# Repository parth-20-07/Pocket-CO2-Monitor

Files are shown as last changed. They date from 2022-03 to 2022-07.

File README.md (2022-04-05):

# Pocket Carbondioxide Monitor

## Features of our AQI Monitor
- Shows the value of carbondioxide level along with Temperature and Humidity.
- Approx. 1.5 hours Battery Backup.
- MicroUSB Type B charging support.

<br>

## How to assemble the project
1. Download the latest version of firmware from the /Firmware folder
2. Edit the Firmware as per the requirement with the help of guide provided in /Firmware/README.md
3. Order the components from the Bill of Materials as per the requirement.
4. Make the Hardware circuit
   1.  Solder them on General Purpose PCB Board using the design below (or)
   2.  Order the PCB by providing the PCB Developer with the gerber file available in /Hardware/PCB_Gerber.zip and solder all the component on it
5.  Upload the firmware on the the hardware

<br>

## How to use the device
1. Press the push button to turn on the device.
2. The device will start with a bootup screen with the company logo.
3. The landing page will show the value of Carbondioxide, Temperature, Humidity of screen.

<center>

## Schematic Design
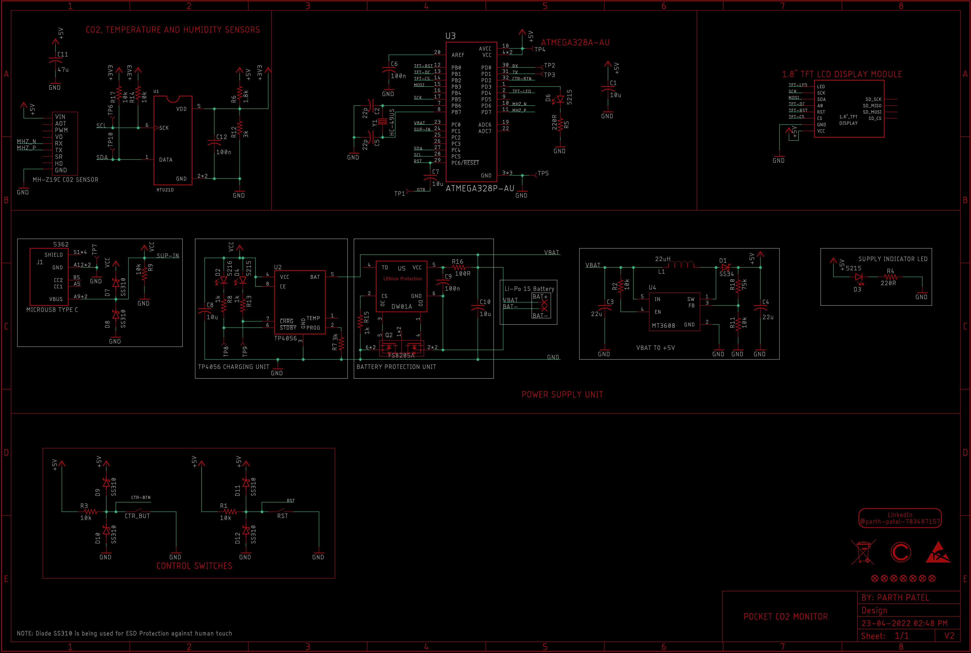
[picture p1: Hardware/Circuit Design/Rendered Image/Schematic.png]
Circuit Schematic

<br><br>

## PCB Design

Top View

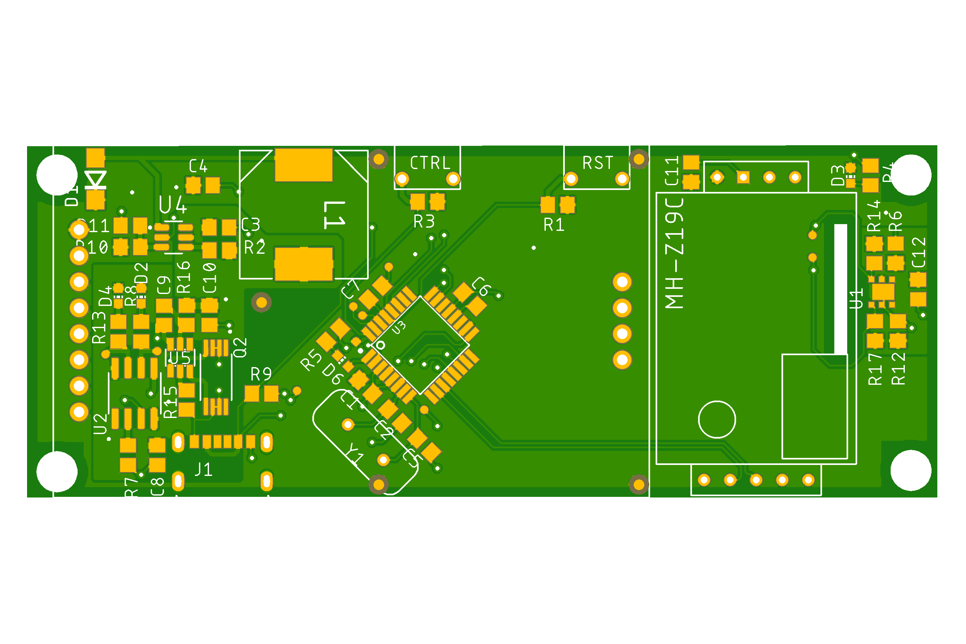
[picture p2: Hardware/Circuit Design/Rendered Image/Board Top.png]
Board Top Design


Bottom View

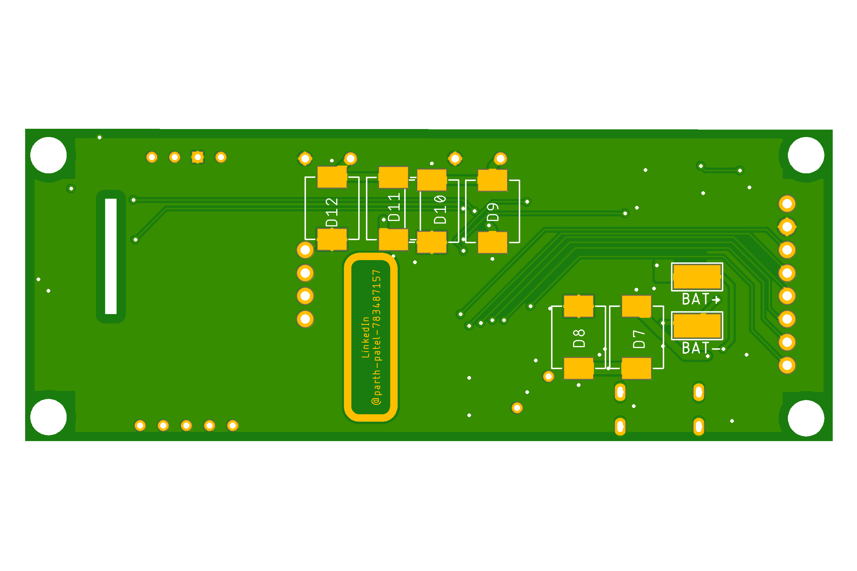
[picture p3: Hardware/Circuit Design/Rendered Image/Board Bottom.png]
Board Bottom Design


## Rendered Images

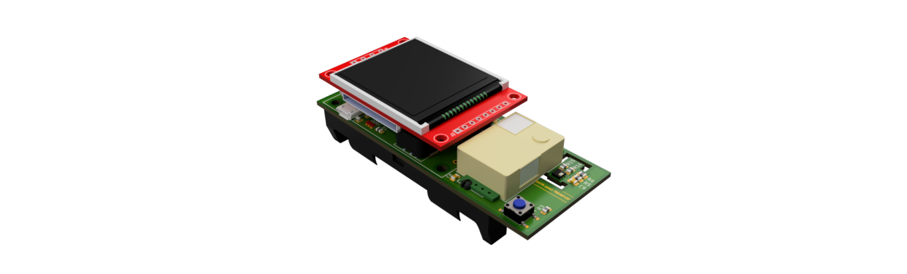
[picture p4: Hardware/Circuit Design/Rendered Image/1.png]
Rendered Design 1


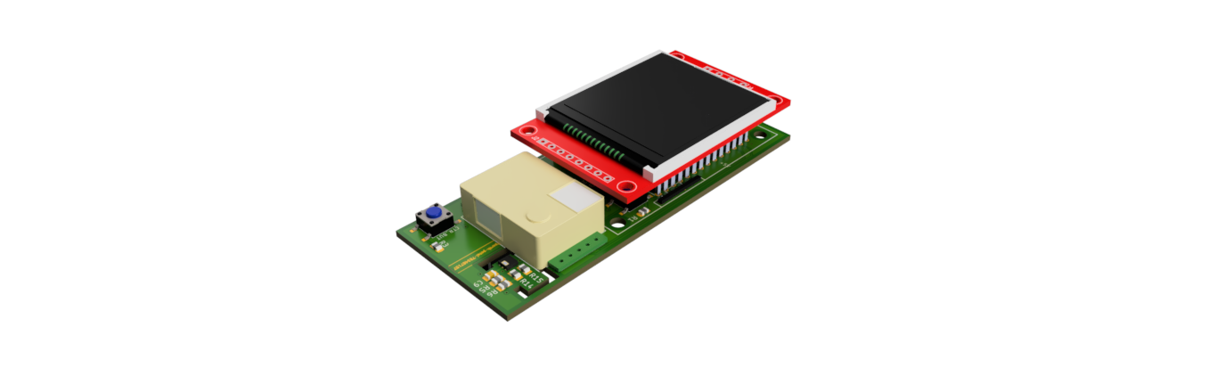
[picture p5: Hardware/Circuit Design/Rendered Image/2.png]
Rendered Design 2


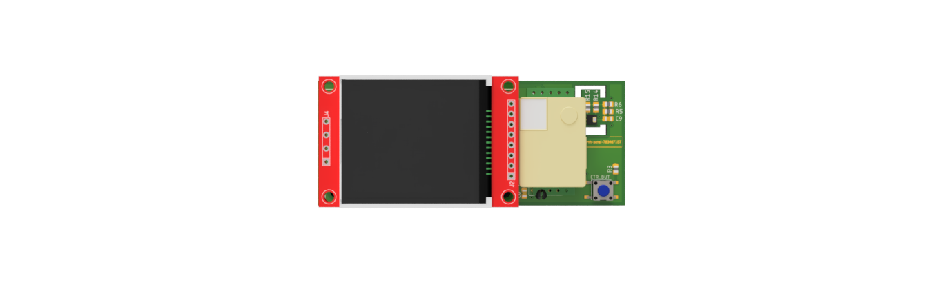
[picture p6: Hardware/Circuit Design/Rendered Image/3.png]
Rendered Design 3


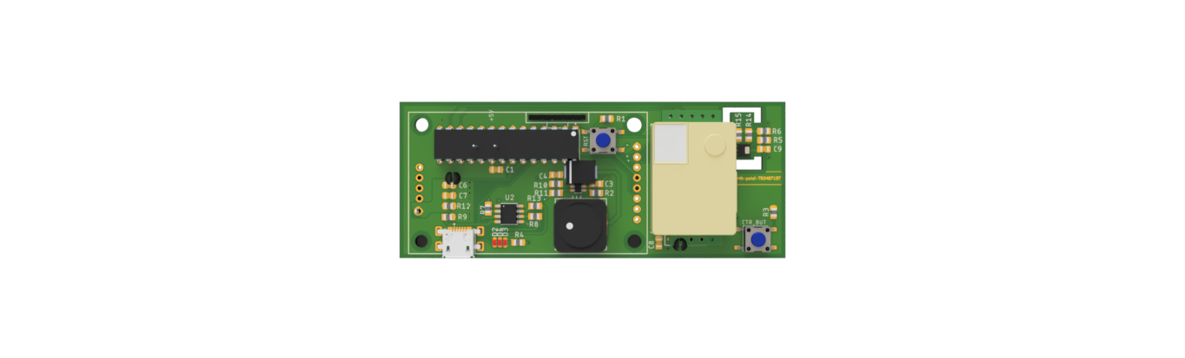
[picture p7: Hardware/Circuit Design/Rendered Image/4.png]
Rendered Design 4


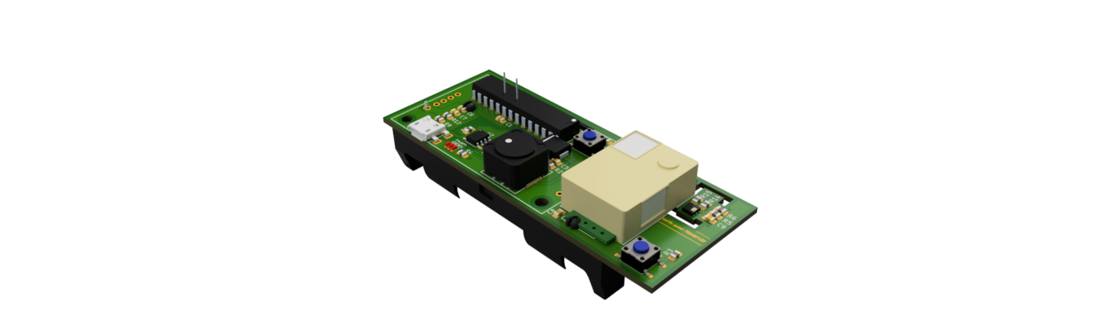
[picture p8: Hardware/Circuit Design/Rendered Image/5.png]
Rendered Design 5


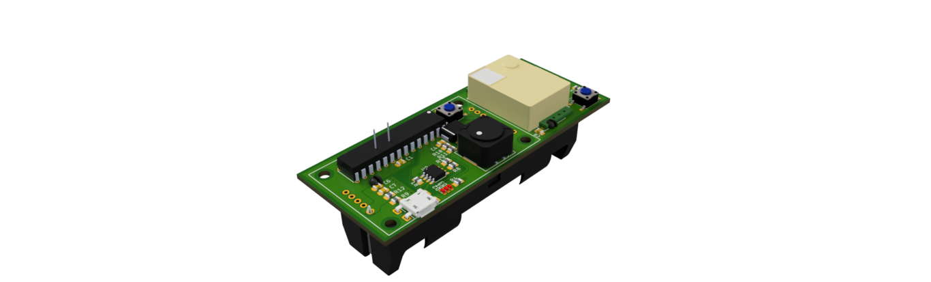
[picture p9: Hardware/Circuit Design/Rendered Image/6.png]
Rendered Design 6


</center>

## Tools Used
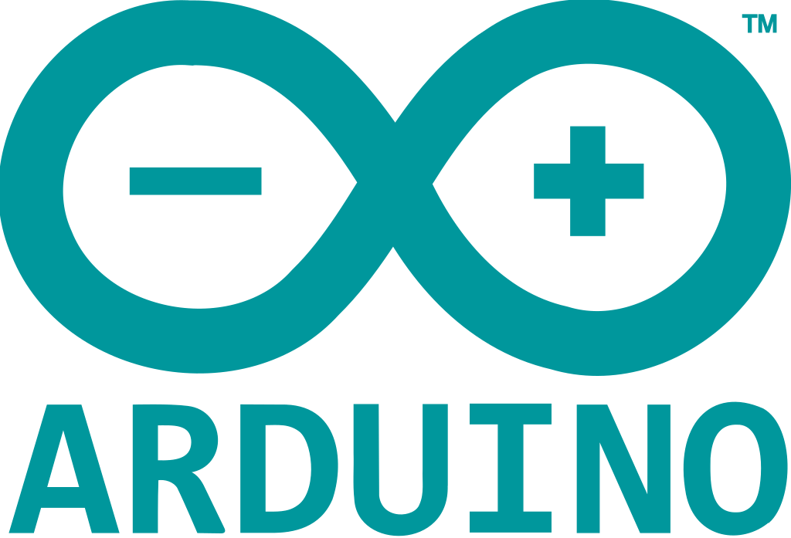
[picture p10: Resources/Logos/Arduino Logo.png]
Arduino
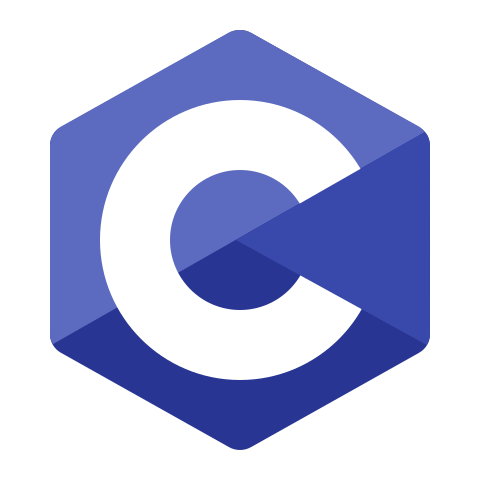
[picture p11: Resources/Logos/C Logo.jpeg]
C
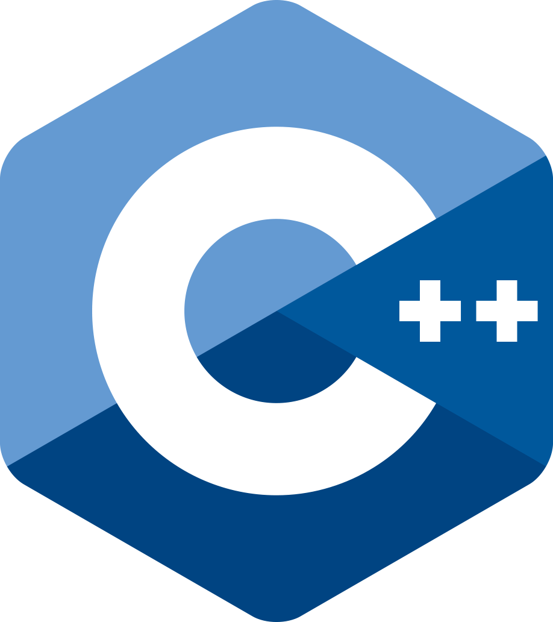
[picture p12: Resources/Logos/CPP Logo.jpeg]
CPP
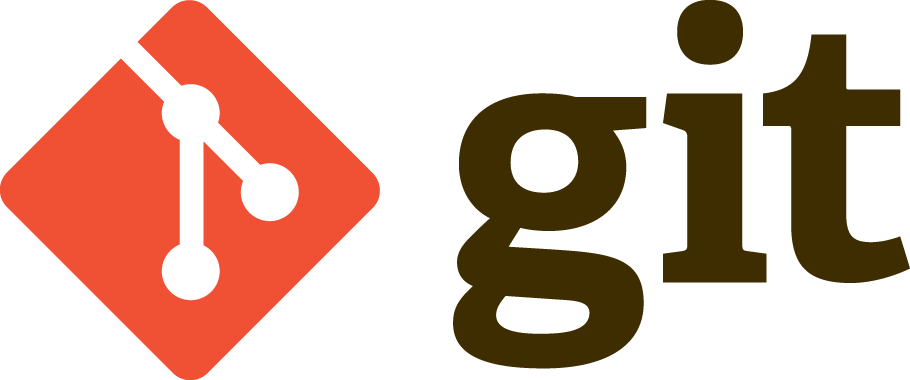
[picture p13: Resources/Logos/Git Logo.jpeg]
Git
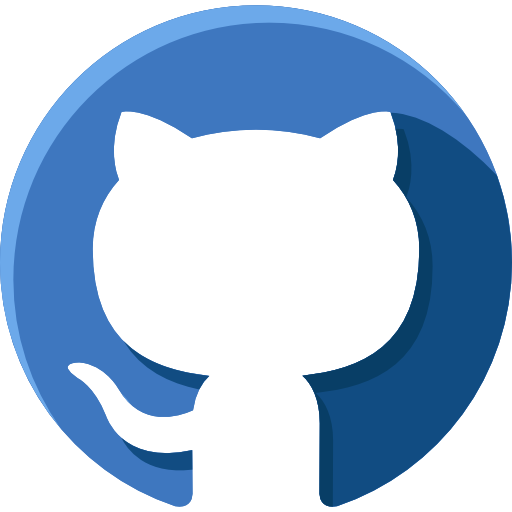
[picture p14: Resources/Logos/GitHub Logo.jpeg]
GitHub
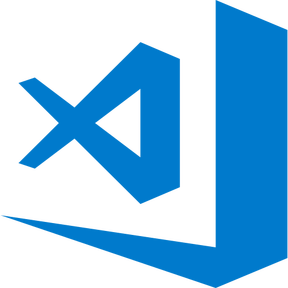
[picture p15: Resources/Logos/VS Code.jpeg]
VS Code
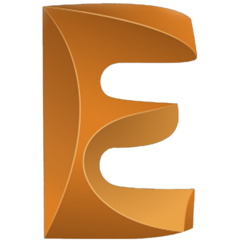
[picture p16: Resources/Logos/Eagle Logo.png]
Eagle
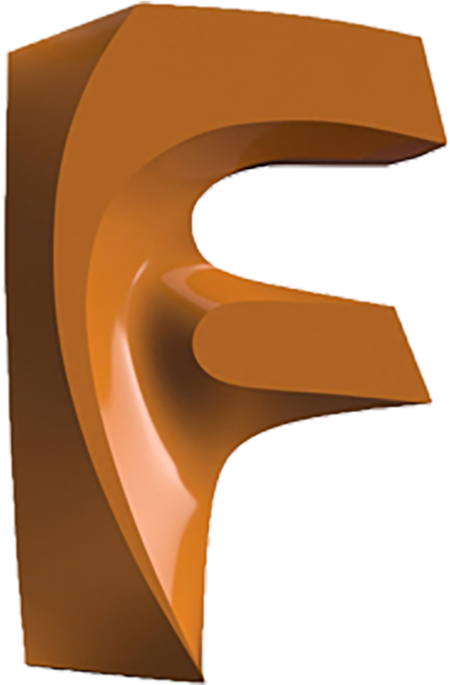
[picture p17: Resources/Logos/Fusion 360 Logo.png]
Fusion 360


<br><br>

## Design Details
- Designed for: Ecologic Pvt. Ltd.
- Designed by: [Parth Patel](mailto:parth.pmech@gmail.com)

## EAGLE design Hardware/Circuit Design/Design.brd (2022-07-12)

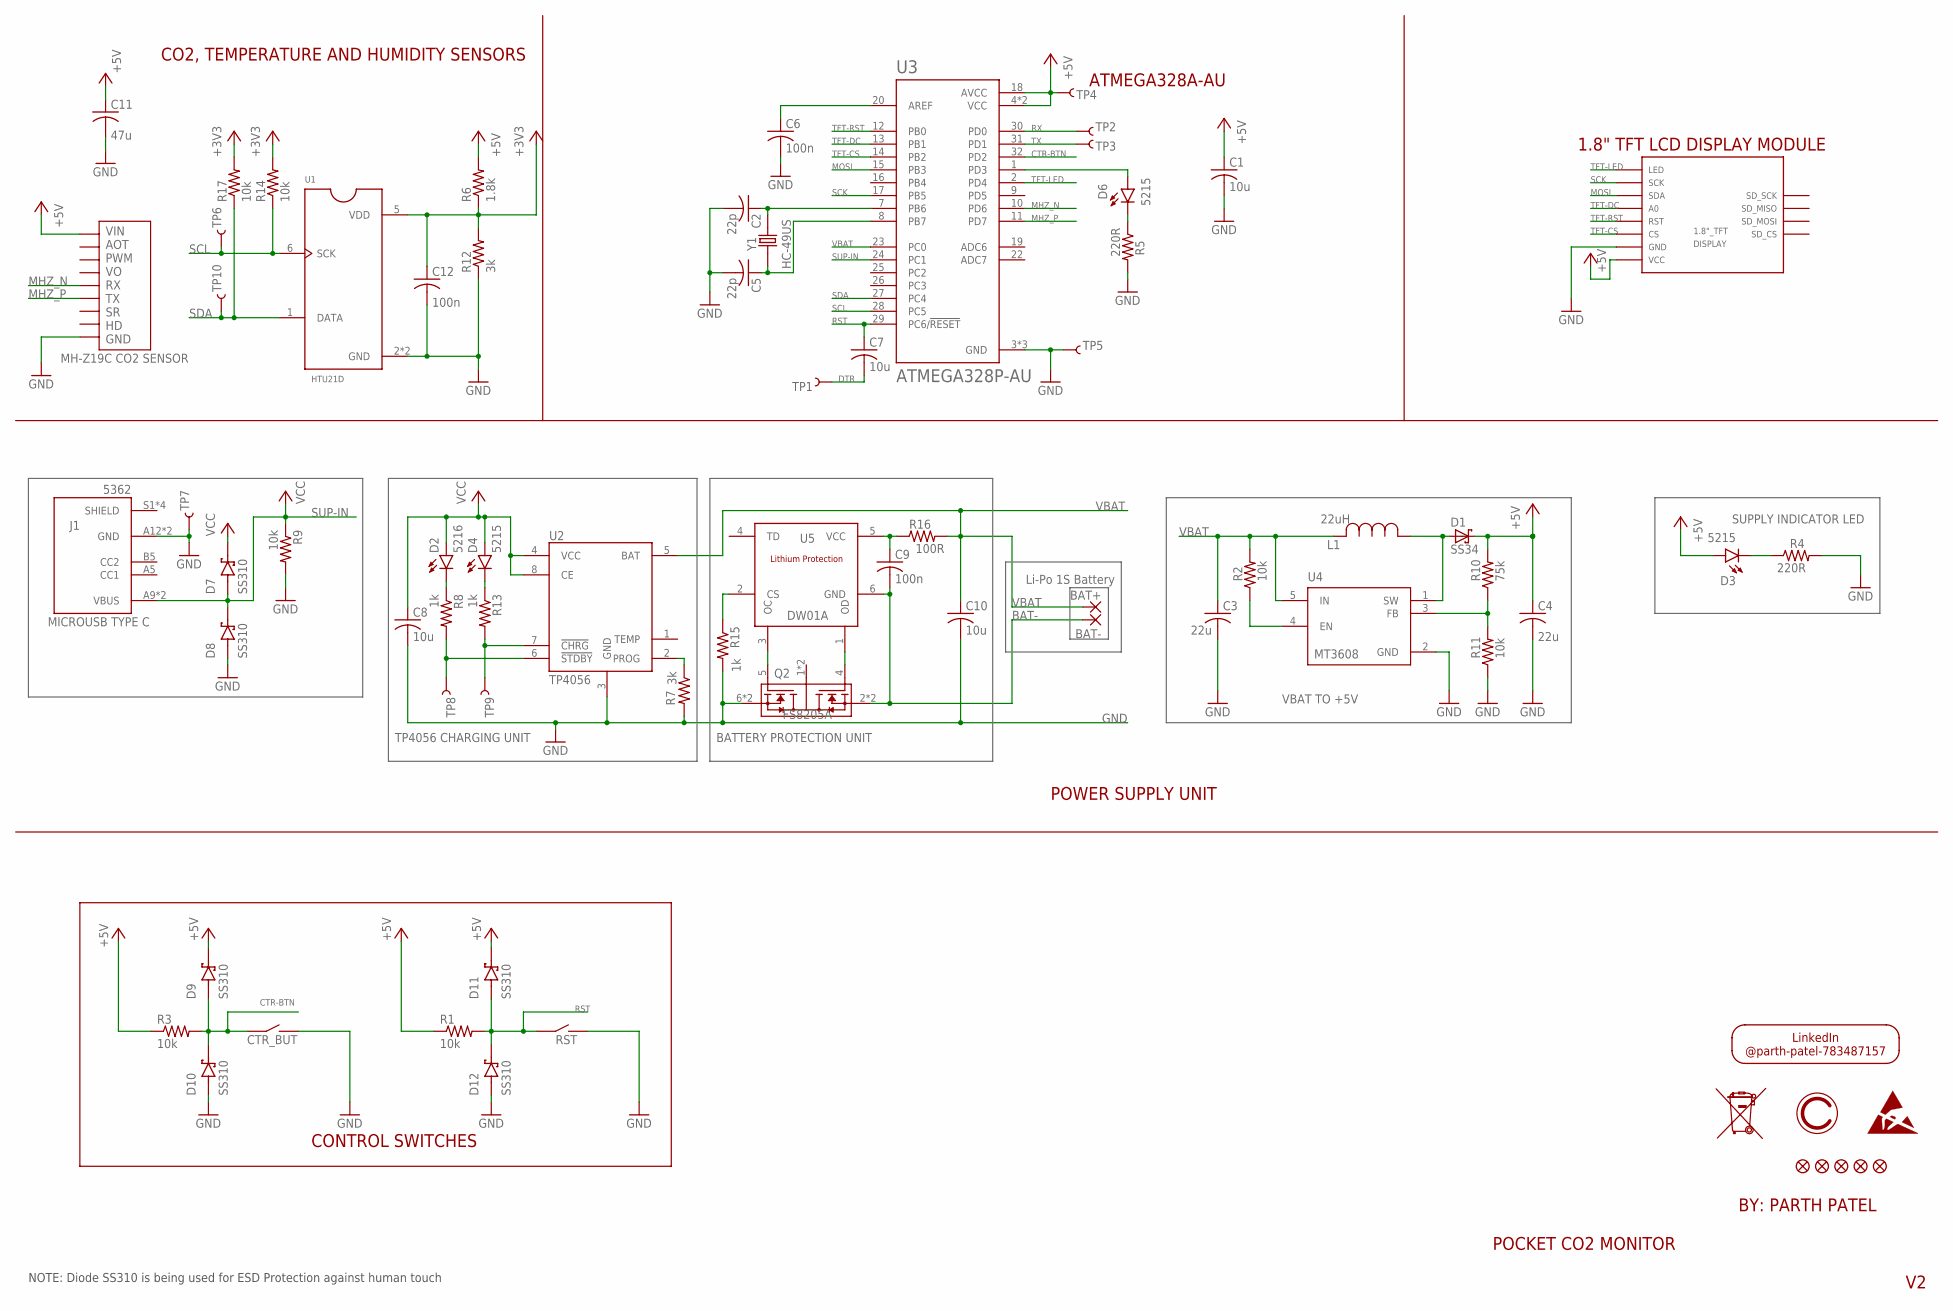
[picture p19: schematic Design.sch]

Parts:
BAT+: WIREPADSMD5-2,5; 5-2,5
BAT-: WIREPADSMD5-2,5; 5-2,5
C1, C7, C8, C10: 10u; C0805
C2, C5: 22p; C0805
C3, C4: 22u; C0805
C6, C9, C12: 100n; C0805
C11: 47u; C0805
CTR_BUT: 7058; DIP_3X6MM_SIDE_PRESS_2PIN
D1: SS34; DO214
D2: 5216; CHIP-LED0603
D3, D4, D6: 5215; CHIP-LED0603
D7, D8, D9, D10, D11, D12: SS310; DIOM6859X262N
DISPLAY: 1.8"_TFT
FID1, FID2, FID3, FID4, FID5: FIDUCIAL""; FIDUCIAL_1MM
J1: 5362; GCT_USB4125-GF-A-0190_REVA2
L1: 22uH; INDM125125X800N
Q2: FS8205A; SOP65P640X120-8N
R1, R2, R3, R9, R11, R14, R17: 10k; R0805
R4, R5: 220R; R0805
R6: 1.8k; R0805
R7, R12: 3k; R0805
R8, R13, R15: 1k; R0805
R10: 75k; R0805
R16: 100R; R0805
RST: 7058; DIP_3X6MM_SIDE_PRESS_2PIN
TP1, TP2, TP3, TP4, TP5, TP6, TP7, TP10: TEST-POINT3; PAD.03X.03
TP8: ~STDBY; PAD.03X.03
TP9: ~CHRG; PAD.03X.03
U1: HTU21D; QFN100P300X300X100-7N
U2: TP4056; SOP127P600X175-9N
U3: ATMEGA328P-AU; QFP80P900X900X120-32N
U4: MT3608; SOT95P280X145-6N
U5: DW01A; SOT23-6
U$1: LOGO_17MM; FOOTPRINT_17MM
U$2: MH-Z19C
Y1: HC-49US; XTAL_ECS-160-20-4X

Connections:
+3V3: C12.1, R6.1, R12.2, R14.2, R17.2, U1.5 (VDD)
+5V: C1.1, C4.1, C11.1, D1.C, D3.A, D9.C (K), D11.C (K), DISPLAY.VCC (+5V), R1.1, R3.1, R6.2, R10.2, TP4.P$1, U3.4 (VCC), U3.6 (VCC), U3.18 (AVCC), U$2.VIN
BAT-: BAT-.1, C9.2, Q2.2 (S1), Q2.3 (S1), U5.6 (GND)
CTR-BTN: CTR_BUT.P$1 (S1), D9.A, D10.C (K), R3.2, U3.32 (PD2)
DTR: C7.2, TP1.P$1
GND: C1.2, C2.2, C3.2, C4.2, C5.2, C6.2, C8.2, C10.2, C11.2, C12.2, CTR_BUT.P$2 (S2), D8.A, D10.A, D12.A, DISPLAY.GND, J1.A12 (GND), J1.B12 (GND), Q2.6 (S2), Q2.7 (S2), R4.2, R5.2, R7.2, R9.2, R11.1, R12.1, R15.2, RST.P$2 (S2), TP5.P$1, TP7.P$1, U1.2 (GND), U1.PAD (GND), U2.3 (GND), U3.3 (GND), U3.5 (GND), U3.21 (GND), U4.2 (GND), U$2.GND
MHZ_N: U3.10 (PD6), U$2.RX
MHZ_P: U3.11 (PD7), U$2.TX
MOSI: DISPLAY.SDA, U3.15 (PB3)
unnamed: C5.1, U3.8 (PB7), Y1.1
unnamed: D3.C, R4.1
unnamed: R2.1, U4.4 (EN)
unnamed: C6.1, U3.20 (AREF)
unnamed: D4.C, R13.1
unnamed: D2.C, R8.1
unnamed: C2.1, U3.7 (PB6), Y1.2
unnamed: D1.A, L1.1, U4.1 (SW)
unnamed: R10.1, R11.2, U4.3 (FB)
unnamed: D6.C, R5.1
unnamed: D6.A, U3.1 (PD3)
unnamed: Q2.5 (G2), U5.3 (OC)
unnamed: R13.2, TP9.P$1, U2.7 (!CHRG)
unnamed: R8.2, TP8.P$1, U2.6 (!STDBY)
unnamed: R7.1, U2.2 (PROG)
unnamed: Q2.4 (G1), U5.1 (OD)
unnamed: R15.1, U5.2 (CS)
unnamed: C9.1, R16.1, U5.5 (VCC)
RST: C7.1, D11.A, D12.C (K), R1.2, RST.P$1 (S1), U3.29 (PC6/!RESET)
RX: TP2.P$1, U3.30 (PD0)
SCK: DISPLAY.SCK, U3.17 (PB5)
SCL: R14.1, TP6.P$1, U1.6 (SCK), U3.28 (PC5)
SDA: R17.1, TP10.P$1, U1.1 (DATA), U3.27 (PC4)
SUP-IN: D7.A, D8.C (K), J1.A9 (VBUS), J1.B9 (VBUS), R9.1, U3.24 (PC1)
TFT-CS: DISPLAY.CS, U3.14 (PB2)
TFT-DC: DISPLAY.DC (A0), U3.13 (PB1)
TFT-LED: DISPLAY.LED, U3.2 (PD4)
TFT-RST: DISPLAY.RST, U3.12 (PB0)
TX: TP3.P$1, U3.31 (PD1)
VBAT: BAT+.1, C3.1, C10.1, L1.2, R2.2, R16.2, U2.5 (BAT), U3.23 (PC0), U4.5 (IN)
VCC: C8.1, D2.A, D4.A, D7.C (K), U2.4 (VCC), U2.8 (CE)

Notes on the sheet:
POWER SUPPLY UNIT
POCKET CO2 MONITOR
BY: PARTH PATEL
CONTROL SWITCHES
ATMEGA328A-AU
1.8" TFT LCD DISPLAY MODULE
MICROUSB TYPE C
VBAT TO +5V
TP4056 CHARGING UNIT
Li-Po 1S Battery
BATTERY PROTECTION UNIT
SUPPLY INDICATOR LED
NOTE: Diode SS310 is being used for ESD Protection against human touch
CO2, TEMPERATURE AND HUMIDITY SENSORS

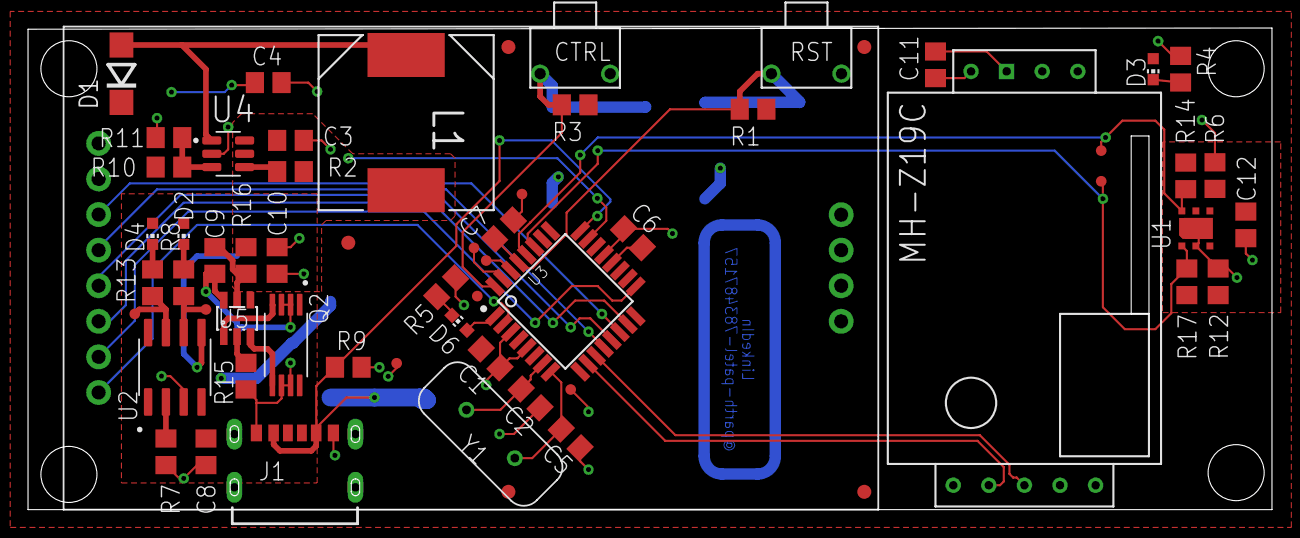
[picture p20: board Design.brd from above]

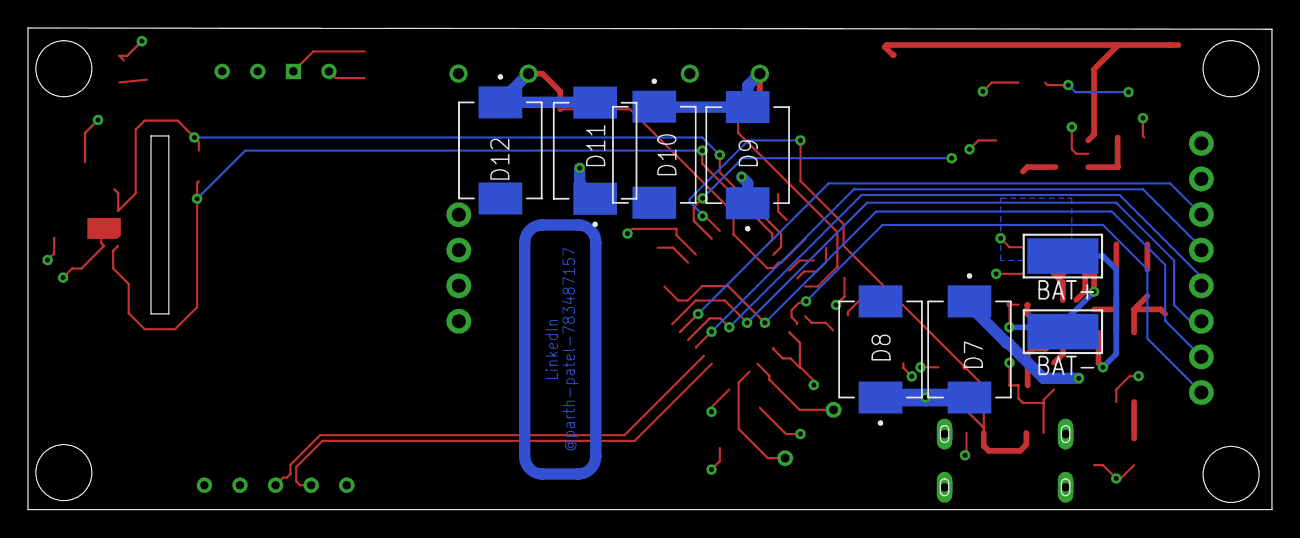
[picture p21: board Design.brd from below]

Board: 2 copper layers, 88.8 x 34.4 mm, 71 parts (9 on the bottom side), 40 nets.

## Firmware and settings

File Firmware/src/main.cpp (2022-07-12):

/**
 * @file main.cpp
 * @author Parth Patel (parth.pmech@gmail.com)
 * @brief
 * @version 0.1
 * @date 2021-12-05
 * @copyright Copyright (c) 2021
 * ! DO NOT CHANGE
 */

//!=============================== BASIC DECLARATION ===============================//
#include <Arduino.h>
#include "Pin_Connection.h"
#include "Variable_Declaration.h"
#include "Sensor_Data_Collection.cpp"
#include <avr/sleep.h>
//!==================================================================================//

//!============================== FUNCTION DEFINITION ==============================//
void boot_screen(void);
void graphic_data_screen(void);
void drawing_battery(void);
void put_device_to_sleep(void);
void change_screen(void);
void stop_device_peripherals(void);

//!==================================================================================//

//!============================== FUNCTION DECLARATION ==============================//
/**
 * @brief Print the Boot Screen on the device startup
 */
void boot_screen(void)
{
  Serial.println("Printing Boot Screen");
  Serial.println("Drawing LOGO");
  screen.background(BLACK_COLOR);
  screen.setTextSize(2);
  screen.stroke(WHITE_COLOR);
  screen.text("ECOLOGIC", 20, (screen_height / 2) - 10);
}

/**
 * @brief Draws the bubble screen for displaying the PM 2.5 Value on the screen
 */
void graphic_data_screen(void)
{
  Serial.println("Starting Device Peripherals");
  digitalWrite(TFT_DISPLAY_LED, HIGH);
  screen.begin();
  screen.setRotation(90);
  screen_width = screen.width();
  screen_height = screen.height();
  screen.background(BLACK_COLOR);
  screen.stroke(WHITE_COLOR);

  change_screen_flag = false;
  Serial.println("Drawing Graphic Screen");
  screen.background(BLACK_COLOR);
  // Design variable declaration
  double indicator_height = 4;
  double indicator_bar_width = screen_width - 4;
  double green_indicator = (MAX_SAFETY_LIMIT * indicator_bar_width) / MAX_HAZARDOUS_LIMIT;
  double warning_indicator = ((MAX_WARNING_LIMIT - MAX_SAFETY_LIMIT) * indicator_bar_width) / MAX_HAZARDOUS_LIMIT;
  double severe_indicator = ((MAX_UNHEALTHY_LIMIT - MAX_WARNING_LIMIT) * indicator_bar_width) / MAX_HAZARDOUS_LIMIT;
  double danger_indicator = ((MAX_HAZARDOUS_LIMIT - MAX_UNHEALTHY_LIMIT) * indicator_bar_width) / MAX_HAZARDOUS_LIMIT;
  uint8_t indicator_x_starting_pos = 2;
  uint8_t indicator_y_starting_pos = (screen_height / 2) + 32;
  uint8_t green_indicator_height = (uint8_t)green_indicator;
  uint8_t warning_indicator_height = (uint8_t)warning_indicator;
  uint8_t severe_indicator_height = (uint8_t)severe_indicator;
  uint8_t danger_indicator_height = (uint8_t)danger_indicator;
  uint8_t seperation_line_height = 25;

  // Writing Company Logo
  screen.stroke(WHITE_COLOR);
  screen.setTextSize(2);
  screen.text(company_name, 2, MARGIN_BUFFER);

  // Drawing seperation line
  screen.stroke(GREY_COLOR);
  screen.line(0, seperation_line_height, (screen_width / 2) - 15, seperation_line_height);
  screen.setTextSize(1);
  screen.text("CO2", (screen_width / 2) - 10, seperation_line_height - 3);
  screen.line((screen_width / 2) + 15, seperation_line_height, screen_width, seperation_line_height);

  // Drawing the indicator Bar
  screen.stroke(GREEN_COLOR);
  screen.fill(GREEN_COLOR);
  screen.rect(indicator_x_starting_pos, indicator_y_starting_pos, green_indicator_height, indicator_height);
  screen.stroke(YELLOW_COLOR);
  screen.fill(YELLOW_COLOR);
  screen.rect(indicator_x_starting_pos + green_indicator_height, indicator_y_starting_pos, warning_indicator_height, indicator_height);
  screen.stroke(ORANGE_COLOR);
  screen.fill(ORANGE_COLOR);
  screen.rect(indicator_x_starting_pos + green_indicator_height + warning_indicator_height, indicator_y_starting_pos, severe_indicator_height, indicator_height);
  screen.stroke(RED_COLOR);
  screen.fill(RED_COLOR);
  screen.rect(indicator_x_starting_pos + green_indicator_height + warning_indicator_height + severe_indicator_height, indicator_y_starting_pos, danger_indicator_height, indicator_height);
  while (1)
  {
    if ((digitalRead(INT_PIN) == LOW) || change_screen_flag)
    {
      change_screen();
      break;
    }

    if (((millis()) - last_millis > GRAPH_PLOT_TIME) || first_boot)
    {
      first_boot = false;
      Serial.println();
      // Calculating values for the design
      int arrow_x_position = 0;
      collect_co2_values();
      collect_temperature_and_humidity_values();
      Serial.println("Values Fetched");
      String co2_str = (String)CO2;
      strcpy(co2_value, co2_str.c_str());
      String temp_str = (String)temp;
      strcpy(temp_value, temp_str.c_str());
      String humi_str = (String)humd + "%";
      strcpy(humi_value, humi_str.c_str());
      Serial.println("Label CO2: " + (String)co2_value);
      Serial.println("Label Temp: " + (String)temp_value);
      Serial.println("Label Humd: " + (String)humi_value);

      if (CO2 < MAX_HAZARDOUS_LIMIT)
        arrow_x_position = indicator_x_starting_pos + (CO2 * indicator_bar_width / MAX_HAZARDOUS_LIMIT);
      else
        arrow_x_position = indicator_x_starting_pos + indicator_bar_width;
      int arrow_y_position = indicator_y_starting_pos - 5;

      drawing_battery(); // Drawing Header: Battery Percentage
      screen.noStroke();

      // Clearing previous values
      screen.stroke(BLACK_COLOR);
      screen.fill(BLACK_COLOR);
      screen.rect(0, arrow_y_position - 9, screen_width, 10);
      screen.rect(0, indicator_y_starting_pos + indicator_height + 5, screen_width, 8);
      screen.rect(0, screen_height - 20, screen_width, 16);

      // Drawing The circle with latest values
      screen.setTextSize(1);
      if (CO2 < MAX_SAFETY_LIMIT)
      {
        screen.stroke(GREEN_COLOR);
        screen.fill(GREEN_COLOR);
        screen.text("SAFE", indicator_x_starting_pos, indicator_y_starting_pos + indicator_height + 5);
      }
      else if (CO2 < MAX_WARNING_LIMIT)
      {
        screen.stroke(YELLOW_COLOR);
        screen.fill(YELLOW_COLOR);
        screen.text("MODERATE", indicator_x_starting_pos, indicator_y_starting_pos + indicator_height + 5);
      }
      else if (CO2 < MAX_UNHEALTHY_LIMIT)
      {
        screen.stroke(ORANGE_COLOR);
        screen.fill(ORANGE_COLOR);
        screen.text("UNHEALTHY", indicator_x_starting_pos, indicator_y_starting_pos + indicator_height + 5);
      }
      else
      {
        screen.stroke(RED_COLOR);
        screen.fill(RED_COLOR);
        screen.text("HAZARDOUS", indicator_x_starting_pos, indicator_y_starting_pos + indicator_height + 5);
      }
      screen.circle(screen_width / 2, (screen_height / 2) - 15, screen_width / 4);

      // Draw the indicator arrow
      screen.line(arrow_x_position, arrow_y_position, arrow_x_position - 4, arrow_y_position - 8);
      screen.line(arrow_x_position, arrow_y_position, arrow_x_position + 4, arrow_y_position - 8);
      screen.line(arrow_x_position - 4, arrow_y_position - 8, arrow_x_position + 4, arrow_y_position - 8);

      // Writing the text on the circle
      screen.setTextSize(2);
      screen.stroke(BLACK_COLOR);
      screen.text(co2_value, (screen_width / 2) - 20, (screen_height / 2) - 20);
      screen.setTextSize(1);
      screen.text("ppm", (screen_width / 2) - 10, (screen_height / 2) + 2);

      // Writing Temperature and Humidity Values
      screen.setTextSize(1);
      screen.stroke(GREY_COLOR);
      screen.text("T:", (screen_width / 4) - 32, screen_height - 20);
      screen.text(temp_value, (screen_width / 4) - 20, screen_height - 20);
      screen.text(".", (screen_width / 4) - 10, screen_height - 28);
      screen.text("C", (screen_width / 4) - 6, screen_height - 20);
      screen.text("H:", ((3 * screen_width) / 4) - 12, screen_height - 20);
      screen.text(humi_value, ((3 * screen_width) / 4), screen_height - 20);
      last_millis = millis();
    }
  }
}

/**
 * @brief Draws the background to plot the values of PM 2.5
 */
void draw_graph_screen(void)
{
  Serial.println("Draw Graph Background");
  collect_co2_values();
  first_boot = true;

  screen.background(BLACK_COLOR);
  screen.stroke(GREY_COLOR);
  screen.line(GRAPH_BUFFER_SCREEN, GRAPH_BUFFER_SCREEN, GRAPH_BUFFER_SCREEN, screen_height - GRAPH_BUFFER_SCREEN);
  screen.line(GRAPH_BUFFER_SCREEN, screen_height - GRAPH_BUFFER_SCREEN, screen_width - GRAPH_BUFFER_SCREEN, screen_height - GRAPH_BUFFER_SCREEN);
  int x_dots = ((screen_width - (2 * GRAPH_BUFFER_SCREEN)) / GRAPH_BUFFER_SCREEN + 1);
  int y_dots = ((screen_height - (2 * GRAPH_BUFFER_SCREEN)) / GRAPH_BUFFER_SCREEN) + 1;
  for (size_t i = 0; i < y_dots; i++)
    for (size_t j = 0; j < x_dots; j++)
      screen.point((j * GRAPH_BUFFER_SCREEN) + GRAPH_BUFFER_SCREEN, (i * GRAPH_BUFFER_SCREEN) + GRAPH_BUFFER_SCREEN);

  screen.stroke(WHITE_COLOR);
  screen.setTextSize(1);
  screen.text("CO2", screen_width - 40, 10);
  screen.text("500 divs", 1, 1);
  screen.text("5 mins", screen_width - 40, screen_height - 10);
  for (size_t i = 0; i < (y_dots / 2) + 1; i++)
    screen.line(GRAPH_BUFFER_SCREEN, screen_height - (2 * i * GRAPH_BUFFER_SCREEN) - GRAPH_BUFFER_SCREEN, GRAPH_BUFFER_SCREEN / 2, screen_height - (2 * i * GRAPH_BUFFER_SCREEN) - GRAPH_BUFFER_SCREEN);
  for (size_t i = 0; i < (x_dots / 2); i++)
    screen.line((2 * i * GRAPH_BUFFER_SCREEN) + GRAPH_BUFFER_SCREEN, screen_height - GRAPH_BUFFER_SCREEN, (2 * i * GRAPH_BUFFER_SCREEN) + GRAPH_BUFFER_SCREEN, screen_height - (GRAPH_BUFFER_SCREEN / 2));
}

/**
 * @brief Plots the graph bars corresponding to value of PM 2.5 after drawing the graph background
 */
void plot_graph_bar(void)
{
  draw_graph_screen();
  change_screen_flag = false;
  Serial.println("Plot Graph");
  last_millis = millis();
  int x_levels = ((screen_width - (2 * GRAPH_BUFFER_SCREEN)) / GRAPH_BUFFER_SCREEN) / 2;
  int y_levels = ((screen_height - (2 * GRAPH_BUFFER_SCREEN)) / (GRAPH_BUFFER_SCREEN * 2));
  int last_graph_position = 0;
  float graph_divisions = 500;
  float scaling_factor = screen_height / (y_levels * graph_divisions);
  screen.stroke(BLACK_COLOR);

  int x_last_pos, y_last_pos;

  while (last_graph_position <= x_levels)
  {
    if (last_graph_position == x_levels)
    {
      draw_graph_screen();
      last_graph_position = 0;
    }

    if ((digitalRead(INT_PIN) == LOW) || change_screen_flag)
    {
      change_screen();
      break;
    }

    collect_co2_values();

    if ((((millis() - last_millis) > GRAPH_PLOT_TIME) || (last_graph_position == 0) || first_boot) && (CO2 > 10))
    {
      Serial.println("CO2: " + (String)CO2);
      // Calculating Bar Values
      int scaled_value = 0;
      int height = 0;
      if (CO2 < MAX_HAZARDOUS_LIMIT)
      {
        scaled_value = CO2 * scaling_factor;
        height = scaled_value;
      }
      else
      {
        scaled_value = screen_height - (2 * GRAPH_BUFFER_SCREEN);
        height = screen_height - (2 * GRAPH_BUFFER_SCREEN);
      }
      int x_pos = GRAPH_BUFFER_SCREEN + (2 * GRAPH_BUFFER_SCREEN * last_graph_position) + 1;
      int y_pos = screen_height - GRAPH_BUFFER_SCREEN - scaled_value;
      int width = (2 * GRAPH_BUFFER_SCREEN) - 1;

      if (CO2 < MAX_SAFETY_LIMIT)
        screen.fill(GREEN_COLOR);
      else if (CO2 < MAX_WARNING_LIMIT)
        screen.fill(YELLOW_COLOR);
      else if (CO2 < MAX_UNHEALTHY_LIMIT)
        screen.fill(ORANGE_COLOR);
      else
        screen.fill(RED_COLOR);
      screen.stroke(BLACK_COLOR);
      screen.rect(x_pos, y_pos, width, height);

      if (last_graph_position == 0)
      {
        x_last_pos = x_pos + (width / 2);
        y_last_pos = y_pos;
      }
      else
      {
        x_pos = x_pos + (width / 2);
        screen.fill(WHITE_COLOR);
        screen.stroke(WHITE_COLOR);
        screen.circle(x_last_pos, y_last_pos, 2);
        screen.circle(x_pos, y_pos, 2);
        screen.line(x_last_pos, y_last_pos, x_pos, y_pos);
        x_last_pos = x_pos;
        y_last_pos = y_pos;
      }

      last_millis = millis();
      last_graph_position++;
    }
  }
}

/**
 * @brief Draws the battery level after measuring the battery level on the screen in upper right corner of screen when called.
 */
void drawing_battery(void)
{
  int xStart = screen_width - BATTERY_SYMBOL_WIDTH - MARGIN_BUFFER;
  int yStart = MARGIN_BUFFER;
  // Clearing previous battery value
  screen.noStroke();
  screen.fill(BLACK_COLOR);
  screen.rect(xStart, yStart, BATTERY_SYMBOL_WIDTH, BATTERY_SYMBOL_HEIGHT);
  // Creating battery Outline
  screen.stroke(WHITE_COLOR);
  screen.rect(xStart, yStart, BATTERY_SYMBOL_WIDTH, BATTERY_SYMBOL_HEIGHT);
  screen.fill(WHITE_COLOR);
  screen.rect(xStart + BATTERY_SYMBOL_WIDTH, yStart + MARGIN_BUFFER, MARGIN_BUFFER, (BATTERY_SYMBOL_HEIGHT - (2 * MARGIN_BUFFER)));

  // Creating Battery Fill
  float val1 = (analogRead(BATTERY_INPUT) - MIN_BATTERY_ADC_VALUE);
  float available_battery_percentage = (val1 * 100) / MAX_BATTERY_ADC_VALUE;
  // Serial.println("Raw Battery Analog value:" + (String)analogRead(BATTERY_INPUT));
  // Serial.println("Battery Level: " + (String)available_battery_percentage);
  float bat_bar_width = (available_battery_percentage * BATTERY_SYMBOL_WIDTH) / 100;
  int battery_bar_width = bat_bar_width;
  // Serial.println("Integer Bar Width:" + (String)battery_bar_width);
  screen.noStroke();

  if (available_battery_percentage < LOW_BATTERY_PERCENT)
    screen.fill(RED_COLOR);
  else if (available_battery_percentage < MEDIUM_BATTERY_PERCENT)
    screen.fill(ORANGE_COLOR);
  else
    screen.fill(GREEN_COLOR);
  screen.rect(xStart + 1, yStart + 1, battery_bar_width - 2, BATTERY_SYMBOL_HEIGHT - 2);
  if (digitalRead(CONNECTED_SUPPLY_PIN))
  {
    // Serial.println("Charger Connected");
    int batxStart = screen_width - (BATTERY_SYMBOL_WIDTH / 2) - MARGIN_BUFFER;
    int batyStart = MARGIN_BUFFER + 1;
    int bat_symbol_width = 2;
    screen.stroke(WHITE_COLOR);
    screen.line(batxStart, batyStart, batxStart - bat_symbol_width, batyStart + (BATTERY_SYMBOL_HEIGHT / 2));
    screen.line(batxStart - bat_symbol_width, batyStart + (BATTERY_SYMBOL_HEIGHT / 2) - 1, batxStart + bat_symbol_width, batyStart + (BATTERY_SYMBOL_HEIGHT / 2) - 1);
    screen.line(batxStart + bat_symbol_width, batyStart + (BATTERY_SYMBOL_HEIGHT / 2) - 1, batxStart, batyStart + BATTERY_SYMBOL_HEIGHT - 2);
    screen.line(batxStart, batyStart + BATTERY_SYMBOL_HEIGHT - 2, batxStart, batyStart);
  }
}

void put_device_to_sleep(void)
{
  Serial.println("Entering Sleep mode");
  boot_screen();
  delay(5000);
  stop_device_peripherals();
  screen_counter = 0;
  change_screen_flag = false;
  cli();
  set_sleep_mode(SLEEP_MODE_PWR_DOWN);
  sleep_enable();
  Serial.println("Placing Device in sleep mode");
  Serial.flush();
  attachInterrupt(digitalPinToInterrupt(INT_PIN), change_screen, LOW);
  interrupts();
  sleep_cpu();
}

void change_screen(void)
{
  sleep_disable();
  detachInterrupt(digitalPinToInterrupt(INT_PIN));
  Serial.println("Button pressed");
  delay(500);

  change_screen_flag = true;
  uint64_t sleep_timer = millis();
  while (digitalRead(INT_PIN) == LOW)
    if ((millis() - sleep_timer) > 2000)
    {
      screen_counter = 3;
      return;
    }

  if (screen_counter < 2)
    screen_counter++;
  else
    screen_counter = 1;
  return;
}

void stop_device_peripherals(void)
{
  Serial.println("Stopping Device Peripherals");
  digitalWrite(TFT_DISPLAY_LED, LOW);
}
//!==================================================================================//

void setup()
{
  Serial.begin(9600);
  Serial.println("\n\n\n----------------------------------------------------------------------------------------");
  Serial.println("Starting Device");
  setup_sensors();
  setup_peripheral_pin_mode();
  Serial.println("Setup Done");
  boot_screen();
}

void loop()
{
  switch (screen_counter)
  {
  case 1:
    Serial.println("\n----------------------------------------------------------------------------------------");
    graphic_data_screen();
    break;

  case 2:
    Serial.println("\n----------------------------------------------------------------------------------------");
    plot_graph_bar();
    break;

  case 3:
    Serial.println("\n----------------------------------------------------------------------------------------");
    put_device_to_sleep();
    break;
  }
}

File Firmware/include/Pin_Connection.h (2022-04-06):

/**
 * @file PIN_CONNECTION.h
 * @author Parth Patel (parth.pmech@gmail.com)
 * @brief Check the Pin Connection on this page as per the connection
 * @version 0.1
 * @date 2021-12-27
 * @copyright Copyright (c) 2021
 * ! DO NOT CHANGE
 */

#ifndef PIN_CONNECTION_H
#define PIN_CONNECTION_H

// GPIO PINS
#define NANO_GPIO_2 2
#define NANO_GPIO_3 3
#define NANO_GPIO_4 4
#define NANO_GPIO_5 5
#define NANO_GPIO_6 6
#define NANO_GPIO_7 7
#define NANO_GPIO_8 8
#define NANO_GPIO_9 9
#define NANO_GPIO_10 10
#define NANO_AI_0 A0
#define NANO_AI_1 A1
#define NANO_AI_2 A2
#define NANO_AI_3 A3
#define NANO_AI_6 A6
#define NANO_AI_7 A7

// COMMUNICATION PINS
#define SERIAL_TX 0
#define SERIAL_RX 1
#define SPI_MOSI 11
#define SPI_MISO 12
#define SPI_SCK 13
#define I2C_SDA A4
#define I2C_SCL A5

/* -------------------------- INTERRUPT CONNECTION -------------------------- */
#define INT_PIN NANO_GPIO_2 // Push Button to change the screens

/* -------------------------- MHZ - 19C CONNECTION -------------------------- */
#define MHZ_RX NANO_GPIO_6 // Serial RX Pin for the MHZ-19C Sensor
#define MHZ_TX NANO_GPIO_7 // Serial TX Pin for the MHZ-19C Sensor

/* ---------------------------- SUPPLY CONNECTION --------------------------- */
#define BATTERY_INPUT NANO_AI_0        // Battery connection input to the Arduino to read the battery level
#define CONNECTED_SUPPLY_PIN NANO_AI_1 // Suppply connection input to the Arduino to read the Charger connection state

/* --------------------------- DISPLAY CONNECTION --------------------------- */
#define TFT_DISPLAY_CS NANO_GPIO_10
#define TFT_DISPLAY_DC NANO_GPIO_9
#define TFT_DISPLAY_RST NANO_GPIO_8
#define TFT_DISPLAY_LED NANO_GPIO_4

void setup_peripheral_pin_mode(void)
{
    pinMode(TFT_DISPLAY_LED, OUTPUT);
    pinMode(INT_PIN, INPUT);
    pinMode(CONNECTED_SUPPLY_PIN, INPUT);
    pinMode(BATTERY_INPUT, INPUT);
}

#endif

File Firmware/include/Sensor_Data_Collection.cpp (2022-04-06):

#ifndef Sensor_Data_Collection_cpp
#define Sensor_Data_Collection_cpp

#include "Arduino.h"
#include "Pin_Connection.h"
#include "Variable_Declaration.h"

/* -------------------------------------------------------------------------- */
/*                              BASIC DEFINITION                              */
/* -------------------------------------------------------------------------- */
#define VALUE_LENGTH 5
#define MINIMUM_WIDTH 1
#define NUM_AFTER_DECIMAL 0

#include <Wire.h>
#include "HTU21D.h"
HTU21D temperature_and_humidity_sensor; // Create an instance of the object
uint8_t humd, temp;
char temp_value[VALUE_LENGTH], humi_value[VALUE_LENGTH]; // Variable to store values

#include "MHZ19.h"
#include "SoftwareSerial.h"
MHZ19 carbondioxide_sensor; // Constructor for library
SoftwareSerial MHZ19CSerial(MHZ_TX, MHZ_RX);
uint16_t CO2;
char co2_value[VALUE_LENGTH]; // Variable to store CO2

/* -------------------------------------------------------------------------- */
/*                             FUNCTION DEFINITION                            */
/* -------------------------------------------------------------------------- */
void setup_sensors(void)
{
    Serial.println("Setting up Sensors");
    Serial.println("Setting up Temperature and Humidity Sensor");
    temperature_and_humidity_sensor.begin();

    Serial.println("Setting up CO2 Sensor");
    MHZ19CSerial.begin(9600);
    carbondioxide_sensor.begin(MHZ19CSerial);
    carbondioxide_sensor.autoCalibration();
}

void collect_temperature_and_humidity_values(void)
{
    // Serial.println("Reading HTU21D");
    humd = temperature_and_humidity_sensor.readHumidity();
    temp = temperature_and_humidity_sensor.readTemperature();
    // Serial.println("Temperature: " + (String)temp + "C");
    // Serial.println("Humidity: " + (String)humd + "%");
}

void collect_co2_values(void)
{
    // Serial.println("Reading MHZ19C");
    CO2 = carbondioxide_sensor.getCO2();
    // Serial.println("CO2: " + (String)CO2 + "ppm");
}

#endif

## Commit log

2022-03-10 Add the Circuit Schematic and PCB design
    [Design.brd, Design.sch]
2022-04-05 Design display for co2 monitor
    [Design.brd, Design.sch]
2022-04-06 Complete the primary testing of the co2 monitor. Battery Visual still pending
2022-04-26 Correct the sleep mode enter function and add the new board design
    [Design.brd, Design.sch]
2022-06-20 Add the product sketch for the monitor
    [Design.brd]
2022-06-24 Correct the charging logo, data update frequency and graph first plotting time
    [Variable_Declaration.h, main.cpp]
2022-06-25 Add Circuit CAD Model
2022-07-12 Change Mounting Holes size from M1.5 to M4
    [Design.brd, Design.sch]
2022-07-12 Add the CAD model of circuit
    [Design.brd]

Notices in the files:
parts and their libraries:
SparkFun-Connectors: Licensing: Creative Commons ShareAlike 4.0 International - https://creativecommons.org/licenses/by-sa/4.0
